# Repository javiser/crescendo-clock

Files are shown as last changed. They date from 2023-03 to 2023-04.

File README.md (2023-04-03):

# Crescendo Clock - an ESP32 based alarm clock to wake up gently

<p align="center">
  <a href="#highlights">Highlights</a> •
  <a href="#how-to-use">How to use</a> •
  <a href="#main-components">Main components</a> •
  <a href="#compiling-and-customizing-the-software">Compiling and customizing SW</a> •
  <a href="#credits-and-acknowledgment">Credits</a><br>
</p>

**A self-made clock with a gentle crescendo wake up alarm**

https://user-images.githubusercontent.com/75809109/229468796-8822e73a-d802-4b9b-99c0-e9e2a0a7bf44.mp4

## Highlights
- Gentle alarm-clock with a crescendo function to wake up slowly and peacefully
- Simplified user interaction with a rotary encoder with a button. No touch display, no need for 10 different buttons
- Convenient WiFi connection via WPS. Credentials are then stored in NVS flash of the board
- Custom 3D printed case
- Integration with home assistant via MQTT messages (i.e. to create a wake up light effect)
- Light sensor to turn off display at adjust the brightness dynamically
- Written in C++ with ESP-IDF framework (no Arduino!) using Platformio + VSCode

## How to use
### Interaction elements
The user interaction with the crescendo clock takes place exclusively with the rotary encoder. This supports four possible actions:
- Left rotation
- Right rotation
- Short press / click
- Long press

Double press / click action is not supported.

### First step: connecting to WiFi
The crescendo clock sets the time automatically when it is connected to a WiFi. Manual time setting is not supported. The first time you power the clock or when the configured WiFi is not available, you will see a red wifi symbol on the right side of the screen:

https://user-images.githubusercontent.com/75809109/229468847-7dcbb47f-4164-47c6-b531-5e9feb42a694.mp4

Rotate the encoder just one click (left or right) and you will see a message "PRESS WPS". Press the WPS button of your router (or select the corresponding option of your specific router model) and wait a little bit until the WiFi connection has been established automatically. WiFi credentials are stored in NVS of ESP32 so that you will not need to repeat this step in the future. Only one credentials set can be stored: if you configure your clock for a different WiFi using the same procedure, the original WiFi credentials will no longer be present in the NVS.

### Using the crescendo clock 
This overview describes the basic usage of the crescendo clock:
| State | Rotation | Short press | Long press |
|---|:---:|:---:|:---:|
| Time | Increase brightness / activate WPS | Set alarm on/off | Enter alarm time |
| Set alarm time  | Change hour / minute of alarm | Next step | Cancel alarm setting |
| Alarm triggered | No effect | Snooze | No effect |
| Alarm snooze | Snooze cancelling sequence | Increase brightness | Snooze cancelling sequence |

Additional comments:
- If the alarm is active for triggering the alarm time is shown, otherwise it is hidden
- If the alarm is active and the remaining time until alarm triggering is less than 9 hours, this remaining "bed time" will be displayed as well
- After snoozing a triggered alarm, the alarm will be triggered again after 5 minutes if the snooze has not been cancelled
- The snooze process will continue indefinitely until it hasn't been cancelled
- The snooze cancelling sequence is like this: rotate the encoder in one direction, then long press the encoder and finally rotate the encoder in the opposite direction, waiting no longer than 3 seconds between steps. You will see one bar above the remaining time until new alarm trigger when the first step of the sequence has been successfully performed and a second bar after the second step. When the final step is performed, the remaining "snooze time" will just disappear and the alarm time will disappear as well (see the video at the beginning of this page)
- After the snooze cancelling sequence the alarm is deactivated until you activate it again manually. You need to set the alarm every single day! Remember, I designed the clock following my ideal concept of a clock and this is the way I like it.

### MQTT integration
The crescendo clock does not subscribe to any MQTT message. Instead, it sends two different messages:
- One message with the topic `wecker/wake_up` when the alarm is triggered. This will be send every time the alarm is triggered, also after the snooze phase.
- Another message with the topic `wecker/alarm_off` when the snooze cancelling sequence is complete and the alarm has been completely deactivated.

## Main components
These are the main electrical components used in this project:
- [Seeed Studio XIAO ESP32C3 board](https://wiki.seeedstudio.com/XIAO_ESP32C3_Getting_Started/)
- [Rotary encoder with board](https://www.ebay.de/itm/173657244984)
- [2.4 inch display with ILI9341 driver](https://www.waveshare.com/2.4inch-lcd-module.htm)
- [DFRobot's DFPlayer Mini](https://www.dfrobot.com/product-1121.html)
- [Light sensor](https://www.adafruit.com/product/2748)
- [Mini-speaker](https://www.ebay.de/itm/313914312809)

See the [detailed description](hardware/README.md) in the hardware folder for more information about schematics, PCB, 3D printed case, detailed assembly instructions and other design considerations.

## Compiling and customizing the software
Basic knowledge about platformio, ESP-IDF development and ESP32 boards is required. This project has been tested only under a Linux environment. In order to compile this project you will need:
- Your populated PCB board with the ESP32C3 board connected to the PC via USB
- Visual Studio Code with platformio extension installed and Espressif platform 6.1 installed. Platform updates may cause the code to break, this happened during development several times. If you want to avoid this, set the line `platform = espressif32@=6.1.0` in the file [platformio.ini](platformio.ini)

Just build and upload the code! If you upload to code to the board with no hardware connected to it (display, encoder, etc.) you should at least be able to see some basic debug messages via Serial Monitor related to the failed WiFi connection.

### Waking melodies and other settings
In this repository there is not any audio file for the waking melody. In the [DFPlyer mini wiki](https://wiki.dfrobot.com/DFPlayer_Mini_SKU_DFR0299) you will find instructions on how to create your own files (see chapter ["Copy your mp3 into you micro SD card"](https://wiki.dfrobot.com/DFPlayer_Mini_SKU_DFR0299#target_6)). I have a folder called `mp3` in the SD-card and inside it a single file called `0001.mp3`. You can add further files and change the value of `melody_nr` in the `settings` struct in [src/clock_machine.hpp](src/clock_machine.hpp) and add the corresponding mp3 file. In case you want a confirmation sound when you activate the alarm, then set the settings variable `alarm_set_confirmation_sound` to true and make sure a (short) `0101.mp3` file exists. This does not work really well, as the DFPlayer doesn't seem to like short audio files, and I will most likely remove this feature in a near future.

Furthermore, you can change also the snooze time (default = 5 minutes) and the "crescendo speed" in the same `settings` structure. These are fixed values and cannot be changed after compilation.

## Credits and acknowledgment
For this project I have used the inspiration and code from many other projects and sources: 
- I looked up and partly copied some code from the official esp-idf examples contained in https://github.com/espressif/esp-idf/tree/master/examples (mainly those related to SNTP, WPS, MQTT and Wifi functions)
- For the rotary encoder I used some code from https://github.com/LennartHennigs/ESPRotary as well as from https://github.com/craftmetrics/esp32-button. The code from https://github.com/DavidAntliff/esp32-rotary-encoder was also a good source of inspiration
- For the finite state machine implementation I borrowed the ideas from https://www.aleksandrhovhannisyan.com/blog/finite-state-machine-fsm-tutorial-implementing-an-fsm-in-c/ as well as from https://stackoverflow.com/questions/14676709/c-code-for-state-machine
- For the DFPlayer module used this datasheet to look up the specifications https://cdn.shopify.com/s/files/1/1509/1638/files/MP3_Player_Modul_Datenblatt.pdf?10537896017176417241. I also found some undocumented functions in the library implementation in https://github.com/DFRobot/DFRobotDFPlayerMini
- [Adafruit](https://www.adafruit.com/) for the many resources I used for the creation of custom fonts and symbols (see a [more detailed description](fonts/README.md) in the resources folder) as well as for the great inspiration from their [PyPortal Alarm Clock](https://learn.adafruit.com/pyportal-alarm-clock), out of which I created a very first concept of this kind of crescendo clock. 

## License
Copyright (c) 2023 javiser
`crescendo-clock` is distributed under the terms of the MIT License.

See the [LICENSE](LICENSE) for license details.

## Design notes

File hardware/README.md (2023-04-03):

# Hardware

<p align="center">
  <a href="#schematics-and-pcb-design">Highlights</a> •
  <a href="#board-assembly">Board assembly</a> •
  <a href="#3d-printed-case">3D printed case</a> •
  <a href="#final-assembly">Final assembly</a> •
  <a href="#modifications">Modifications</a><br>
</p>

## Schematics and PCB design
<p float="left">
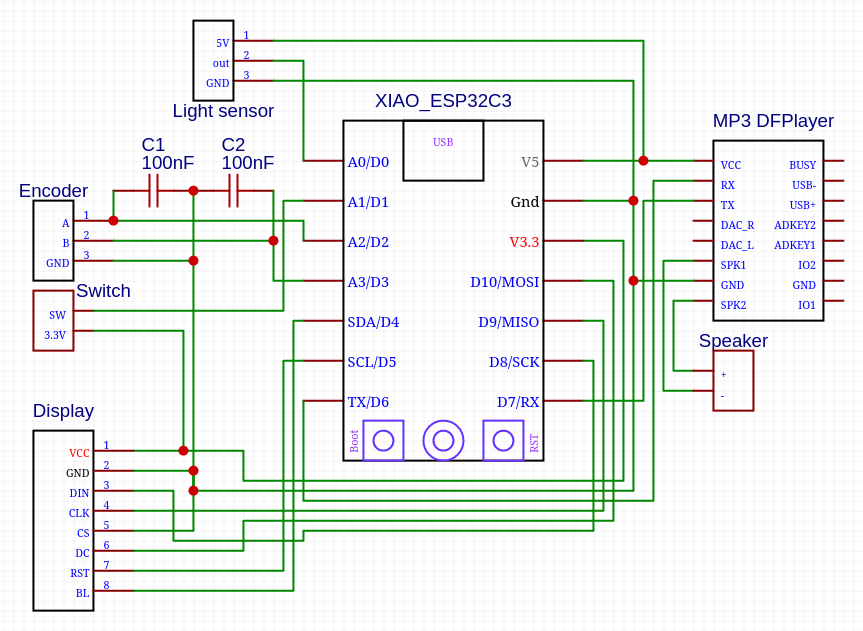
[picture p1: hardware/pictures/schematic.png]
    
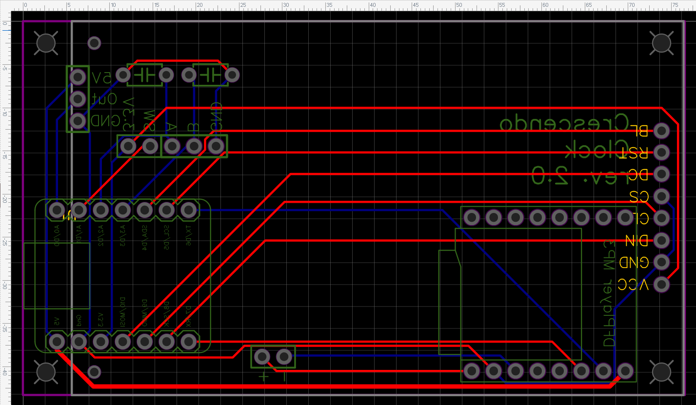
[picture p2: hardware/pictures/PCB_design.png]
    
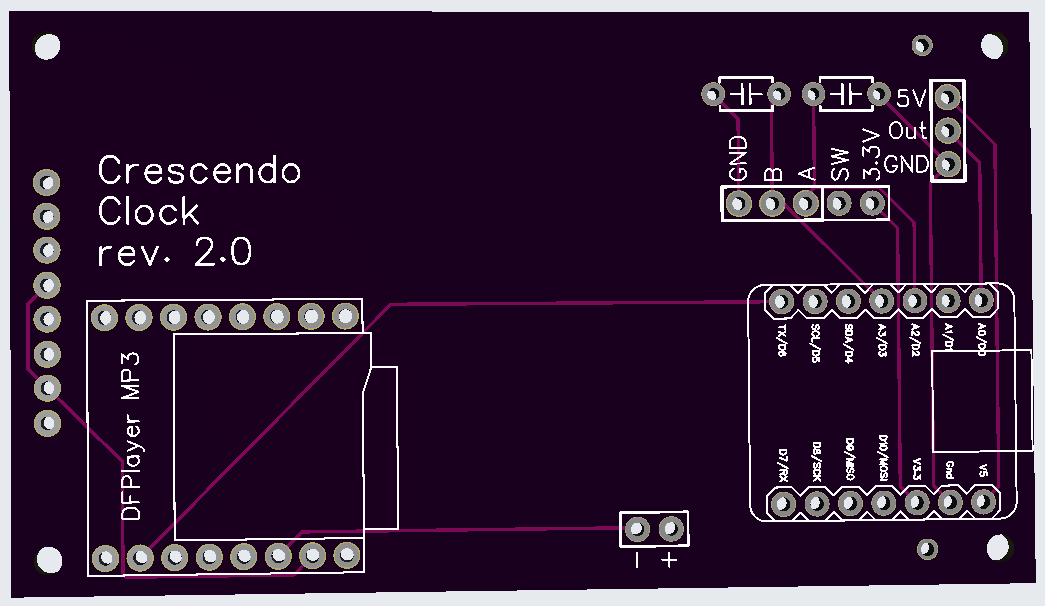
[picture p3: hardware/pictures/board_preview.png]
    
</p>

A couple of mentions to design considerations:

- The capacitors were used in a previous design to add some debouncing. In the current [rotary encoder](https://www.ebay.de/itm/173657244984) used, these capacitors are already include and are not soldered anymore
- With the exception of some SPI pins for the [display](https://www.waveshare.com/2.4inch-lcd-module.htm) and the fact that the light sensor needs an analog input, which pins to use on the ESP32 board should is actually a very free decision
- The design was made using EasyEDA and the [created GERBER files](PCB/Gerber_PCB_Crescendo_Clock_Board_rev2.0.zip) and the board manufactured by [JLCPCB](https://jlcpcb.com). This is the result:

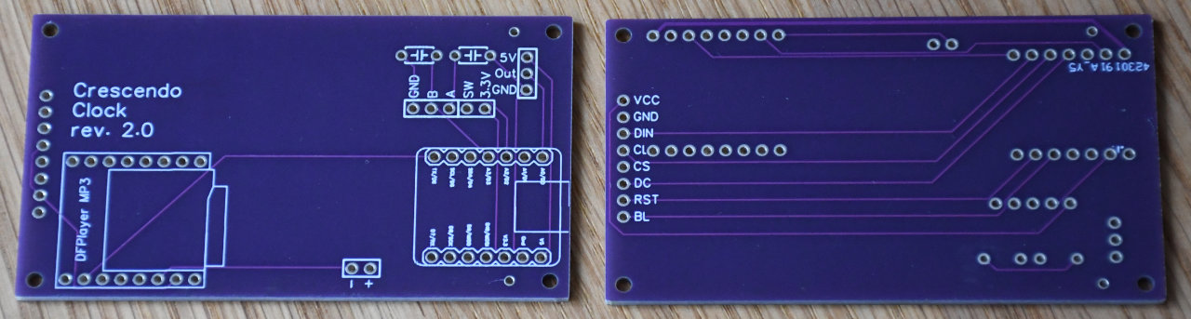
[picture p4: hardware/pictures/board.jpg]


## Board assembly

### Display connector removal
The big connector on the rear side of the display is not needed and needs to be removed in order to build the board properly. Just cut the the pins with some pliers and then you can slide out the connector:
<p float="left">
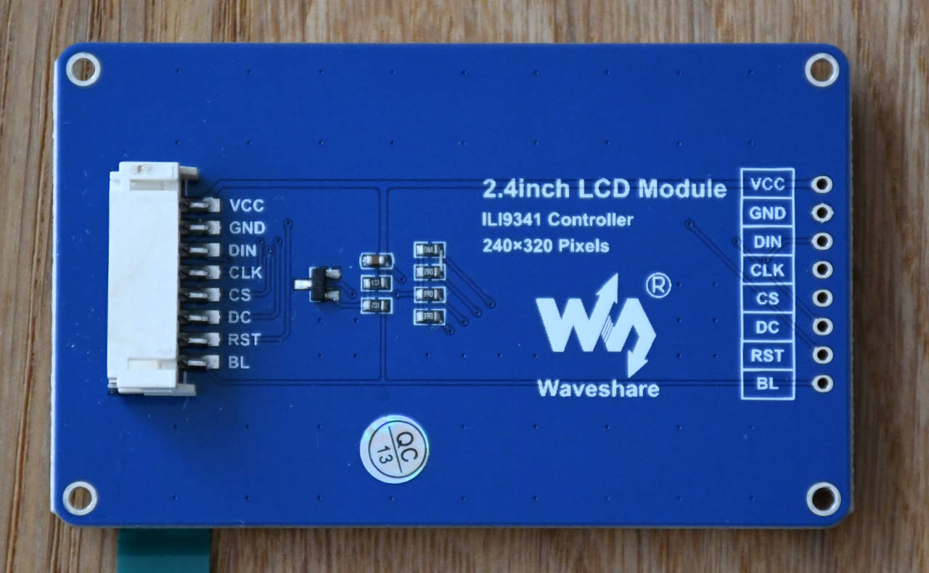
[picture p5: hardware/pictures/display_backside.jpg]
    
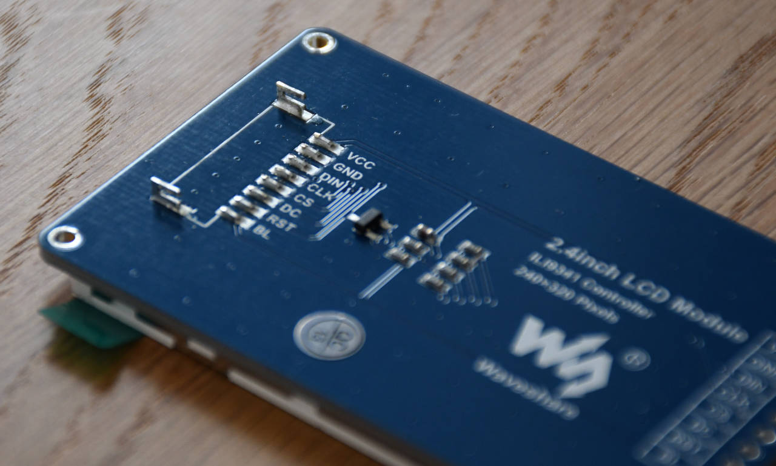
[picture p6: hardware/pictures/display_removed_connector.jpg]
    
</p>

### Soldering all together
1. Solder the 1x8 pin male header on the display and 2 additional 1x1 ones as support. You can use the still empty PCB board as a holder:
<p float="left">
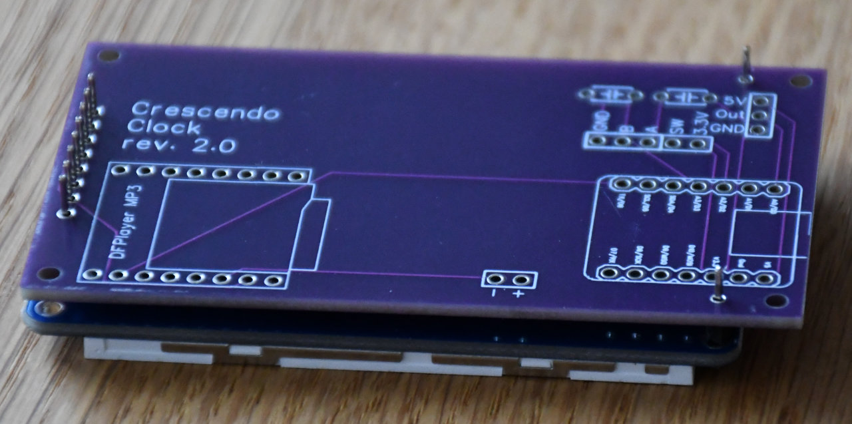
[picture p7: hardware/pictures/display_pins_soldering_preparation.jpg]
    
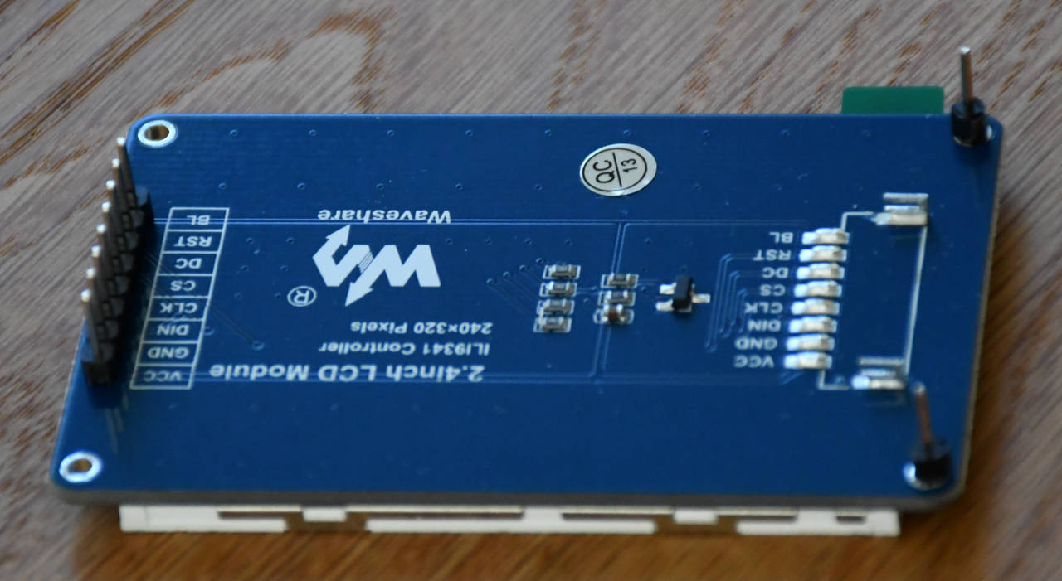
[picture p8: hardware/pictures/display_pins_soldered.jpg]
    
</p>

2. Solder a 1x3 90° pin male header on the [light sensor breakout board](https://www.adafruit.com/product/2748). Pay attention to the orientation!
<p float="left">
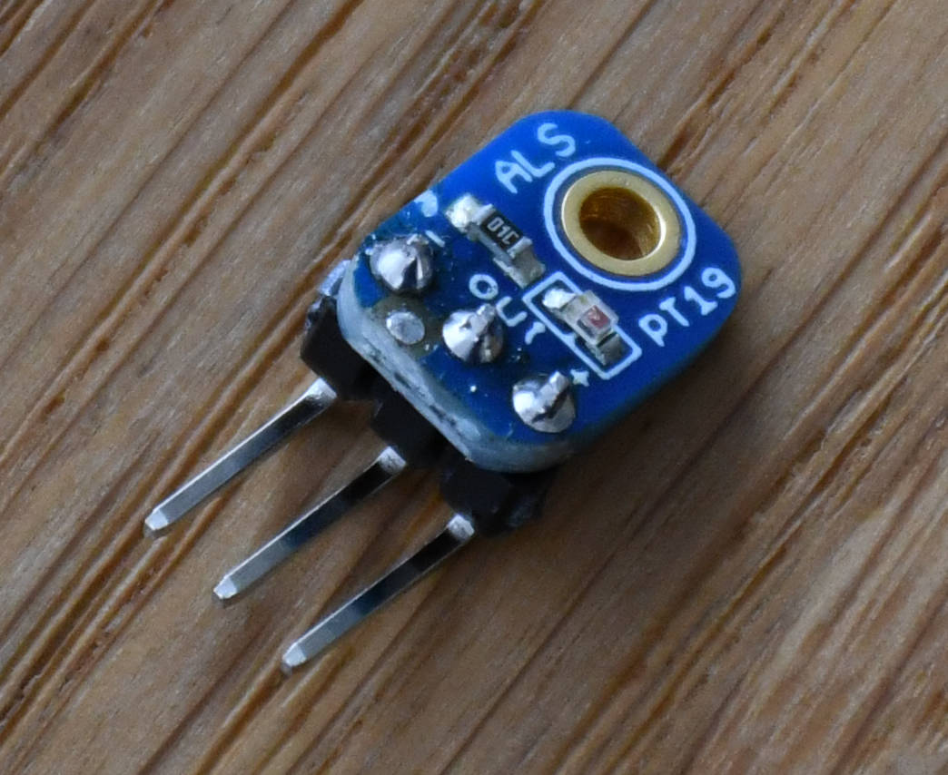
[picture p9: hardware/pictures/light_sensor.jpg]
    
</p>

3. Solder all components to the PCB board and trim the excess length of the pins to make room for the display board
<p float="left">
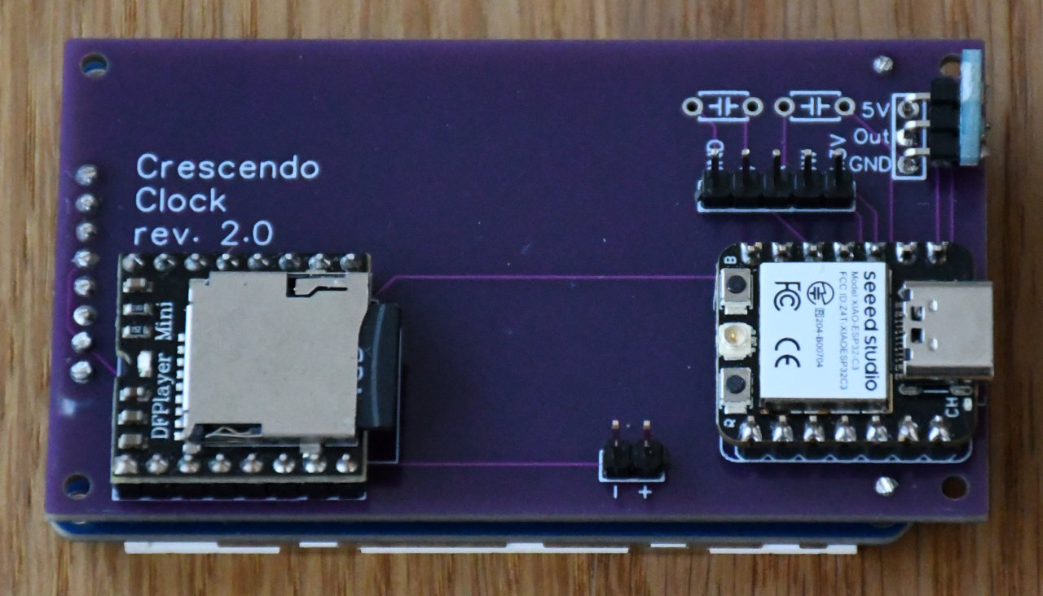
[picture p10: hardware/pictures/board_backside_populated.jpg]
    
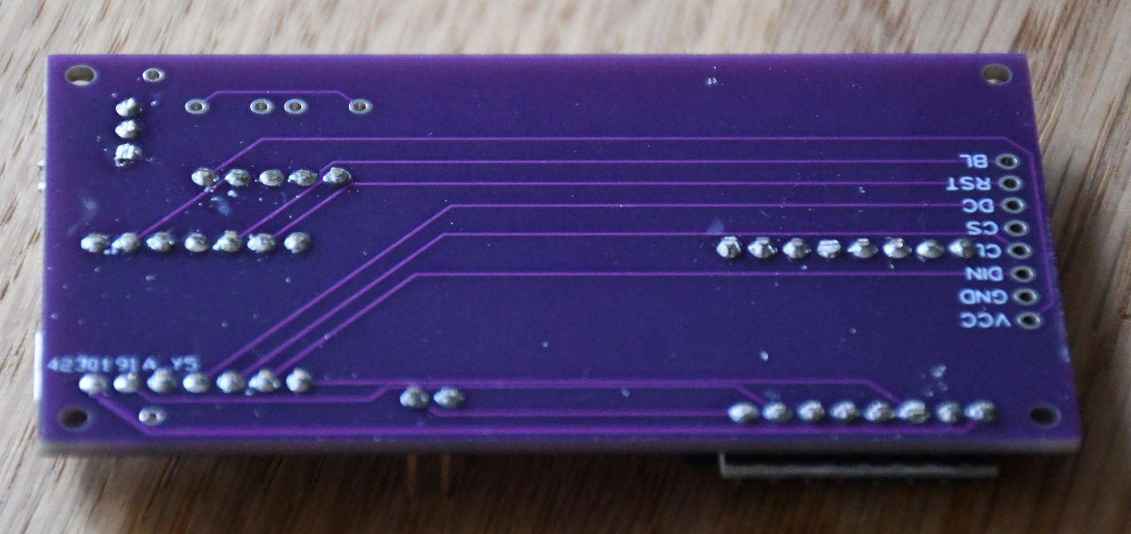
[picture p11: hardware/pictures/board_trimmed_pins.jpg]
    
</p>

4. Solder the display on the other side of the board. 
<p float="left">
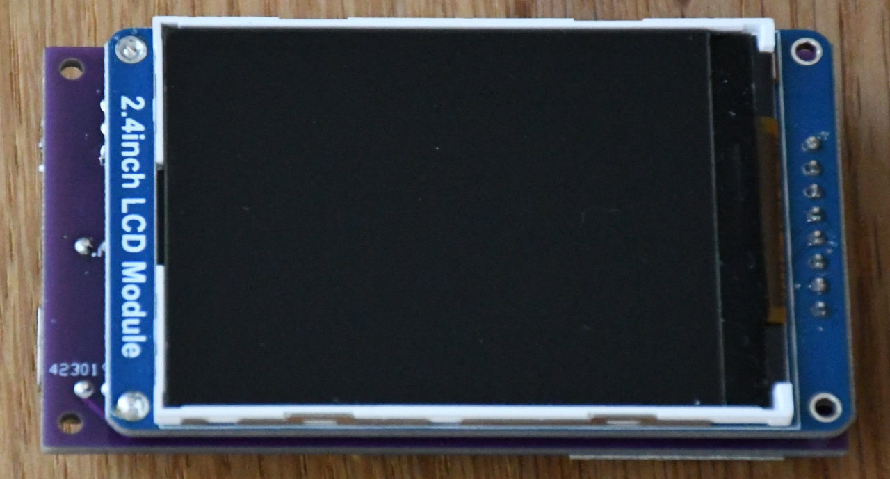
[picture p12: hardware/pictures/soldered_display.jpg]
    
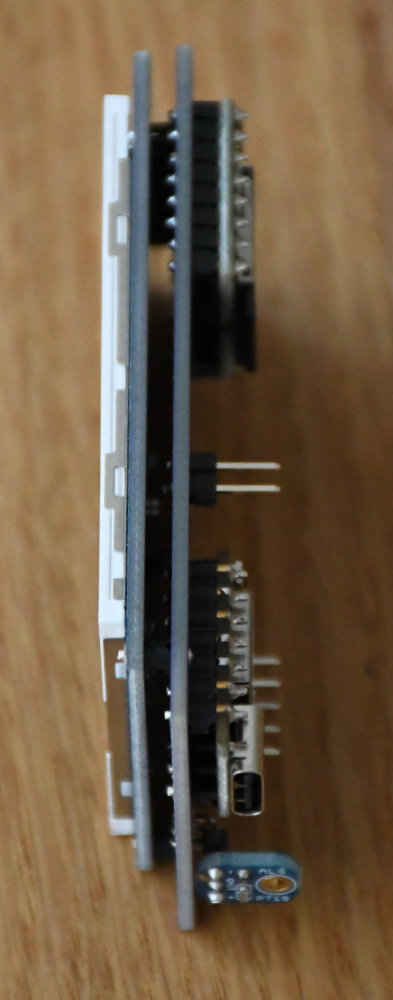
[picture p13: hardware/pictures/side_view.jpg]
    
</p>

5. Prepare a connection cable with 5 pins for the connection between the board and the rotary encoder breakout. Again, I used dupont connectors for this:

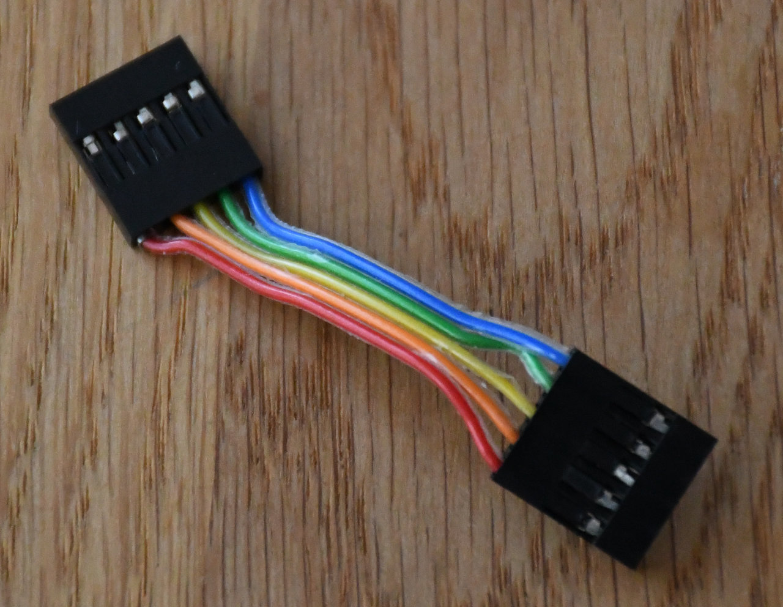
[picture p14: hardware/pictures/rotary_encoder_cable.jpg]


6. If necessary, change the connector of the mini-speaker. I used dupont connectors for this:
   
<p float="left">
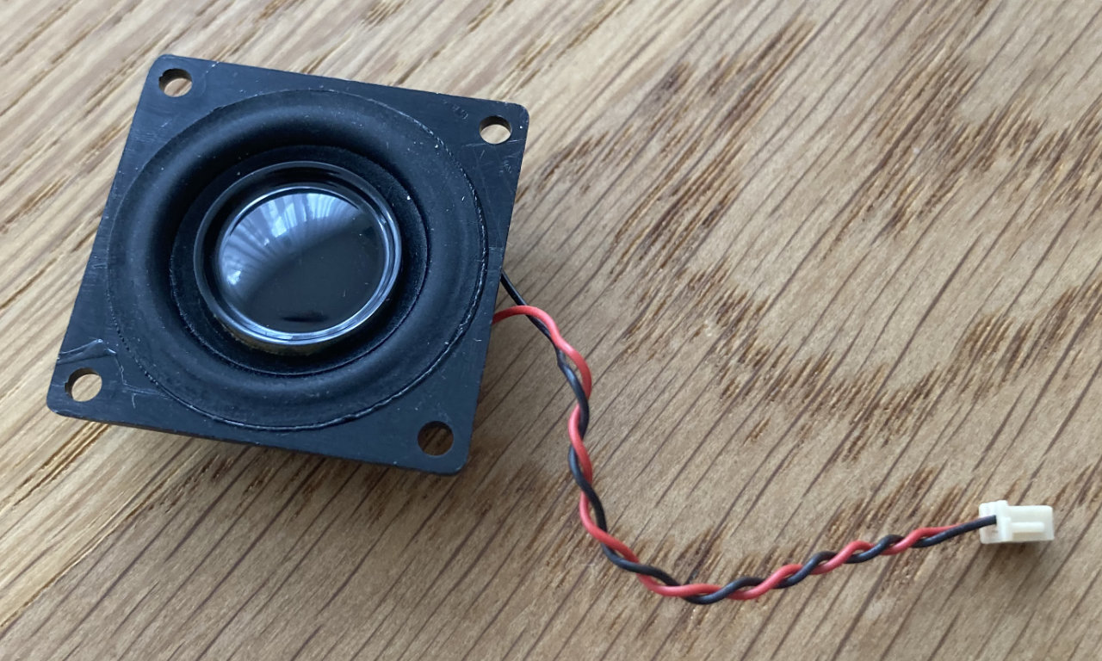
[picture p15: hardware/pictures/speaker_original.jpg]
    
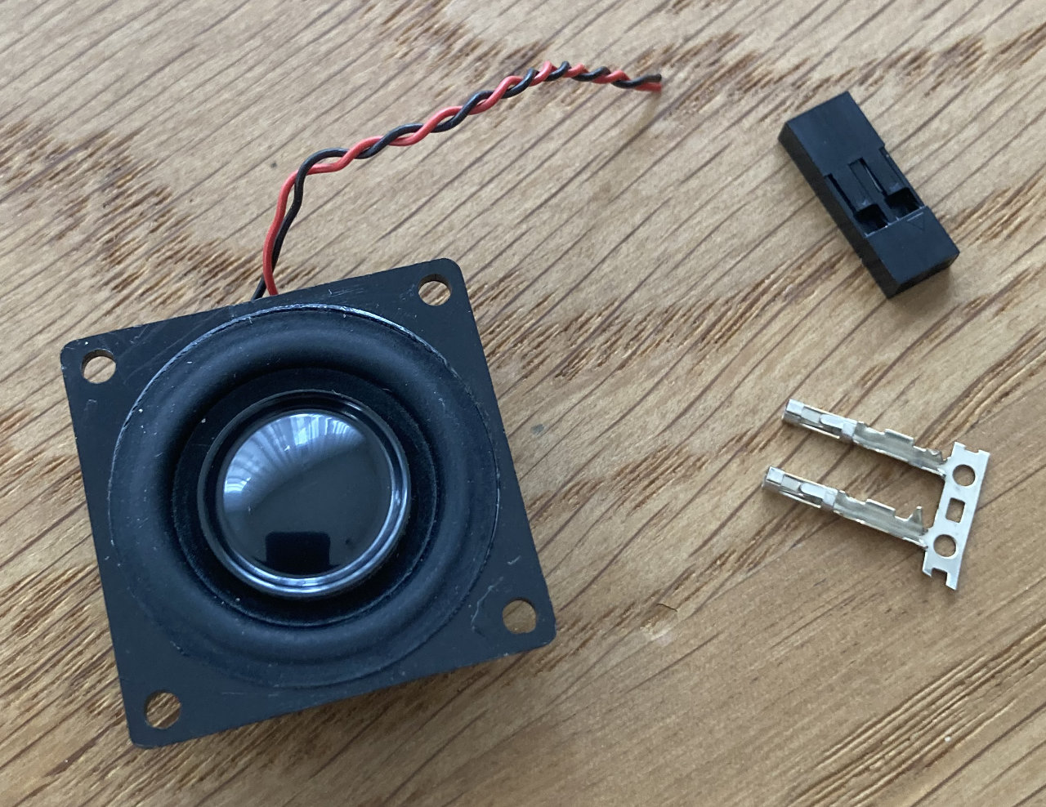
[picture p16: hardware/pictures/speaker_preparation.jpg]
    
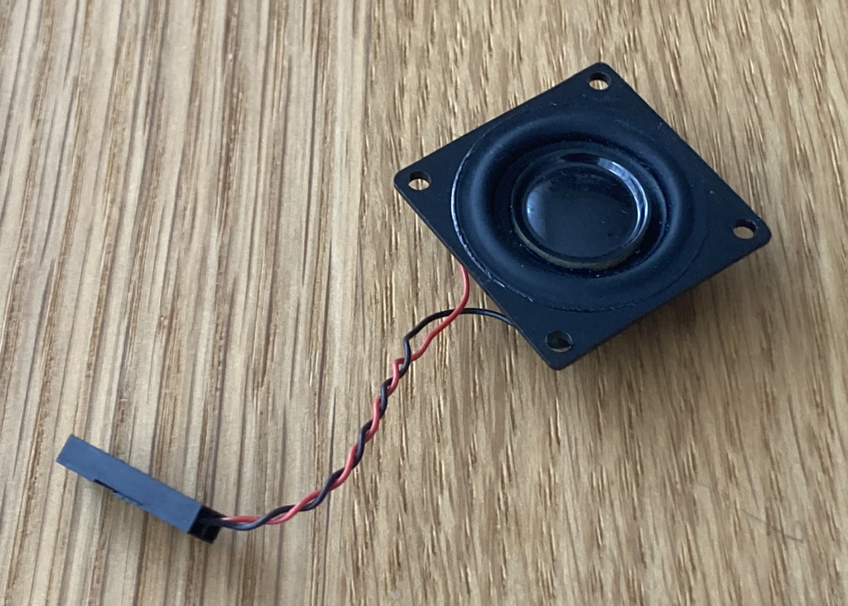
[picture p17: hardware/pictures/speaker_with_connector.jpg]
    
</p>

7. After that it would be a good time to do a sanity check and connect everything together, flash the SW into the board and check whether everything is working as expected:
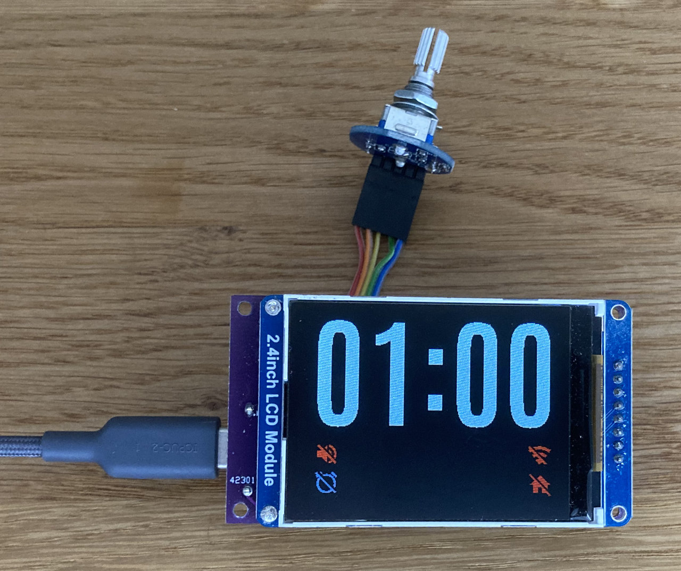
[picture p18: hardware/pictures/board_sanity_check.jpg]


## 3D printed case
STL files for the [case](3D/case.stl), the [rear cover](3D/rear_cover.stl) and the [knurled rotary botton](3D/knurled_button.stl) are available:
<p float="left">
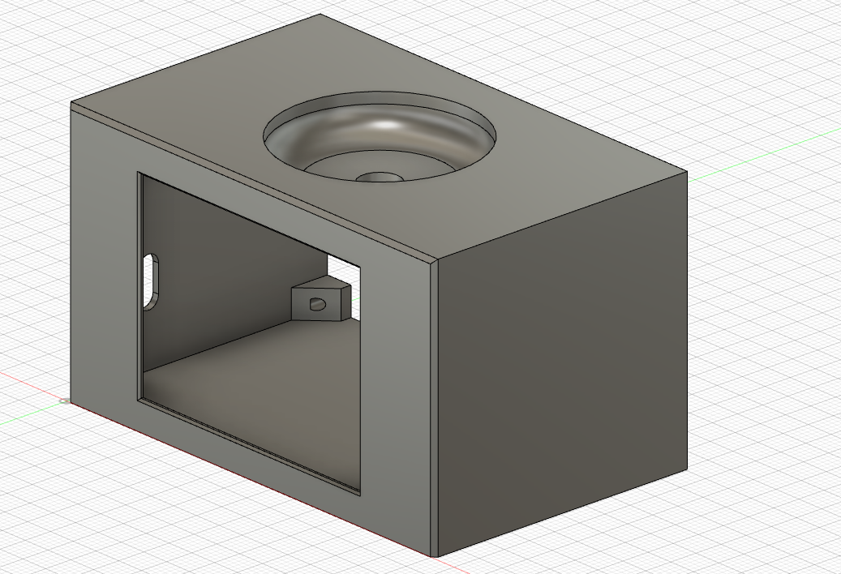
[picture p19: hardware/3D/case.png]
    
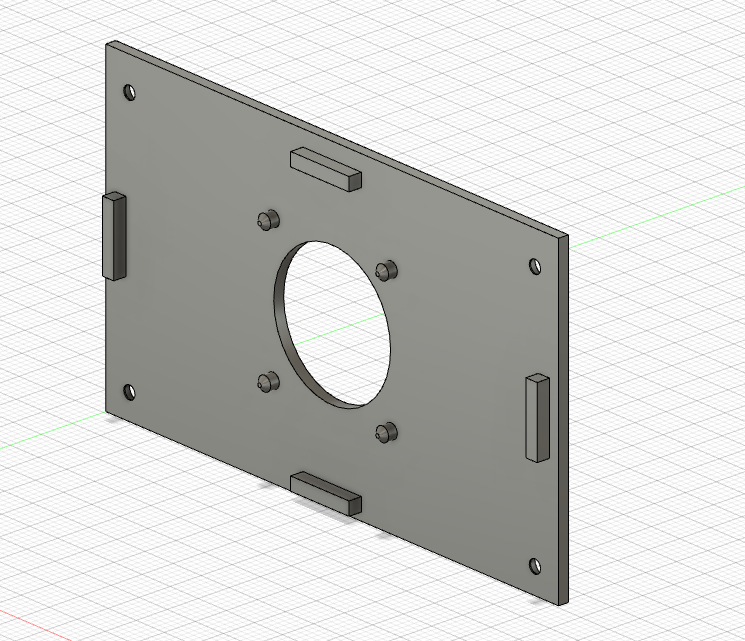
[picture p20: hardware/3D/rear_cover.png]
    
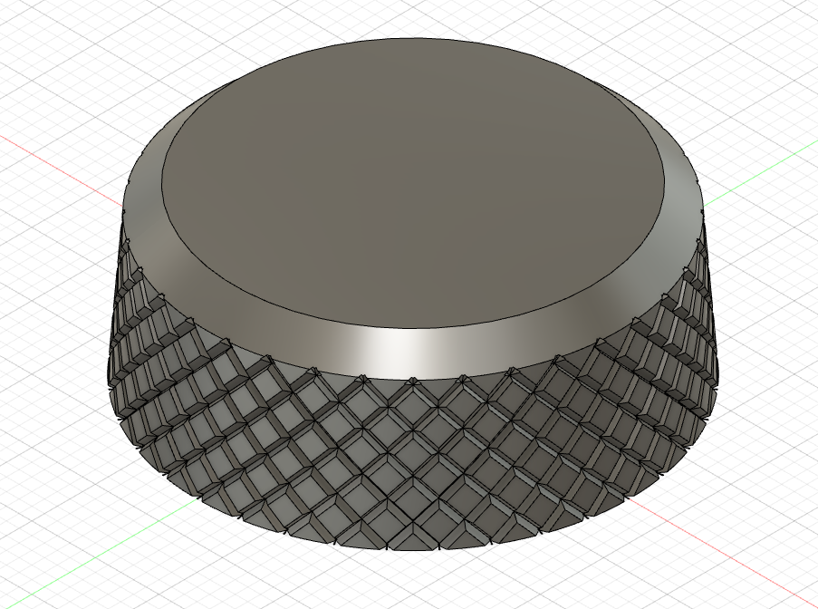
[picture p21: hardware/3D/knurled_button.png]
    
</p>
I printed these with PLA using an Ender 3 v2. Pay attention to the orientation when slicing: the clock front side, the outside face of the rear cover as well as the top face of the button should be your first layer. You may use supports for the big case, I didn't use any and it went ok.

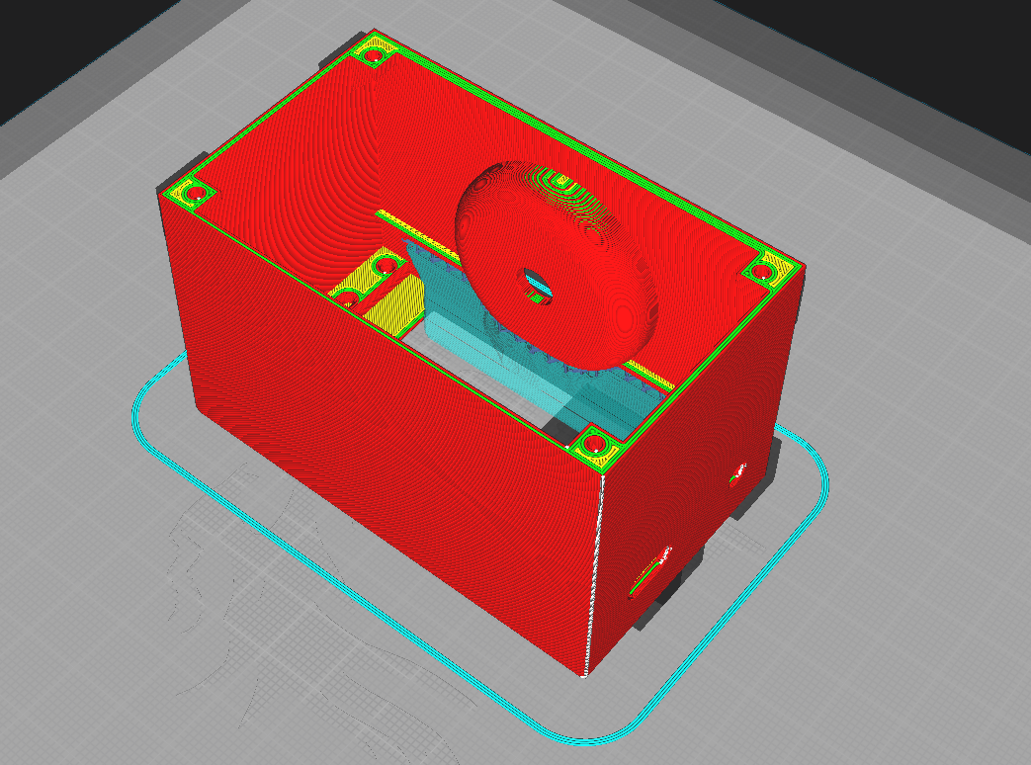
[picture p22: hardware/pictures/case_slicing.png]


You can find the original Fusion 360 files in the [3D folder](3D) as well.

## Final assembly

1. Put an SD card with the necessary audio files. See <a href="../#waking-melodies-and-other-settings">Waking melodies and other settings chapter</a> of the main README for more instructions.
2. Slide in the finished board and screw it into the case using 4 M2.5x8 screws

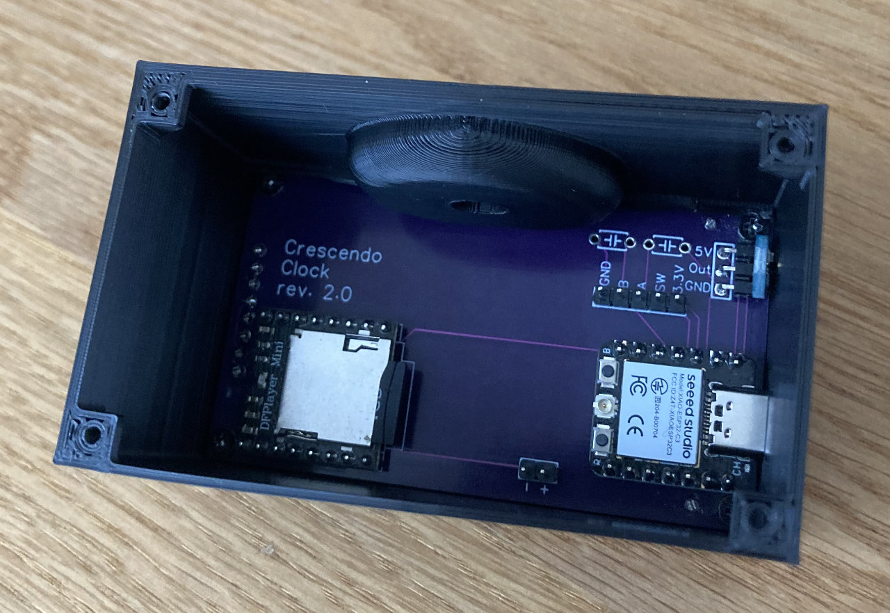
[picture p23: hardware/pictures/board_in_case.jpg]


3. Attach the ESP32 antenna on one side of the case and connect it to the board

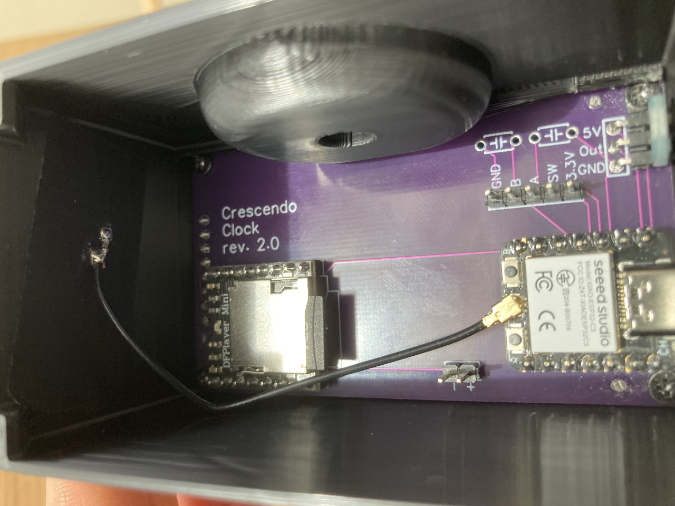
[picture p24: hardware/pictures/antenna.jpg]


4. Connect the cables to the rotary encoder and slide it into its place. Put the washer and hex nut and tighten it. Make sure it is perpendicular. Insert the button into the shaft



5. Attach the speaker on the rear cover. Pay attention to the orientation, since the rear cover has an upper and a lower part and you want the cables coming out of the lower part. It should be a tight fit into the pins, otherwise use some strong glue to make sure it stays attached



6. Connect everything together sure everything is connected  



7. Close the cover using 4 M2x4 screws

## Modifications
The components used are just what I could get my hands on or what made sense to me. Here some considerations:

- It should be possible to use any other ESP32 board. The previous version used the [ESP-C3-32S-Kit ESP32 WiFi+Bluetooth Development Board](https://www.waveshare.com/esp-c3-32s-kit.htm). You just need to make sure that you have at least 11 pins available. The pin assignments defined in [clock_common.hpp](src/clock_common.hpp) will most likely need an adjustment. If you take a variant different from the ESP32C3 you might require more extensive changes as well
- Other LCD displays could work as well, specially if the same ILI9341 driver is used, but maybe other settings are required. Since the used library LovyanGFX supports a lot of different displays, changing to another display is just a matter of adjusting the configuration and, if the resolution changes, the layout (font sizes, symbol and text positions)
- In general any other component like the rotary encoder, speaker or the light sensor should be exchangeable with no or little effort

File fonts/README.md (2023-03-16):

# Fonts and symbols

## Sources for fonts and symbols
The fonts used in this projects have been downloaded from https://fonts.google.com/specimen/Antonio and then customized using FontForge (see chapter below for instructions):
- [Antonio-Semibold](Antonio-SemiBold.ttf) is used for the time visualization. The glyphs have been modified to have a constant width
- [Antonio-Regular](Antonio-Regular.ttf) is used for the "secondary" times: alarm, snooze and bed times. Also the symbols have been embedded into this font and the glyphs have been modified to have a constant width as well
- [Antonio-Light](Antonio-Light.ttf) is used only for the "PRESS WPS" message and has not been customized or modified at all

The [symbols](symbols) are material design icons from https://pictogrammers.com/library/mdi/ which have been imported as glyphs in the fonts

## Tooling

The main tool used for the fonts and symbols customization is [FontForge](https://fontforge.org/en-US/). With this tool it is possible (amongst many other things!) to:
- Remove unnecessary glyphs
- Change the glyph width to allow for consistent spacing and layout
- Import icons and symbols, in our case in SVG format, to be able to print symbols as if they were characters
- Modify these glyphs: scaling, rotating, etc. and create new symbols this way
- Generate a new TTF file for further processing

When the customized fonts are finished, the required characters can be converted to a header file which can be included directly in the code, using the [fotoconvert tool from Adafruit](https://github.com/adafruit/Adafruit-GFX-Library/tree/master/fontconvert). First build the program with `make` and then execute these scripts to generate the required header files:
```
./fontconvert Antonio-SemiBold.ttf 75 48 58 > Antonio_SemiBold75pt7b.h
./fontconvert Antonio-Regular.ttf 26 32 70 > Antonio_Regular26pt7b.h
./fontconvert Antonio-Light.ttf 16 69 87 > Antonio_Light16pt7b.h
```
Please note that it is necessary to specify a range of characters. For big fonts it is necessary to pay attention to the flash size of the generated fonts. The fotoconvert tool does not support multiple ranges, which could help minimize the size of the files.

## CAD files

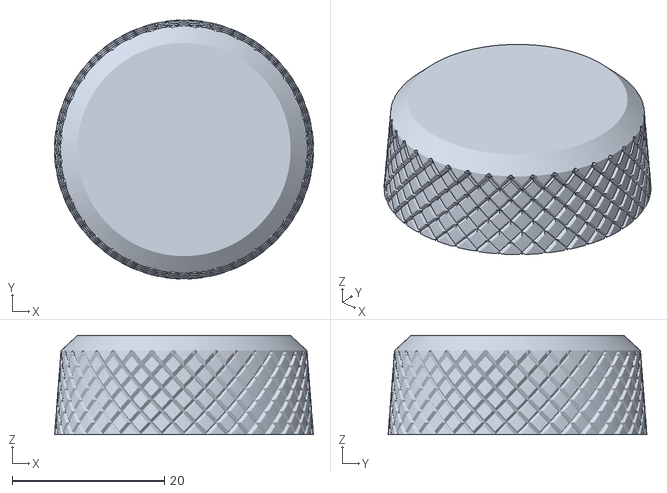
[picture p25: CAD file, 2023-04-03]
hardware/3D/knurled_button.stl
34.0 x 34.0 x 13.0

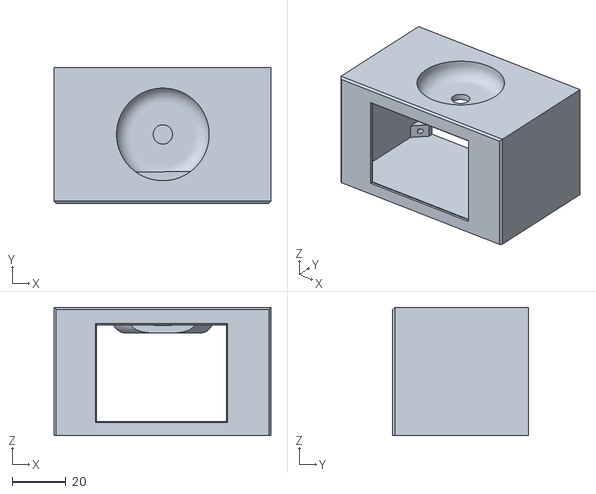
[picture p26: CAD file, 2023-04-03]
hardware/3D/case.stl
80.6 x 50.4 x 47.7

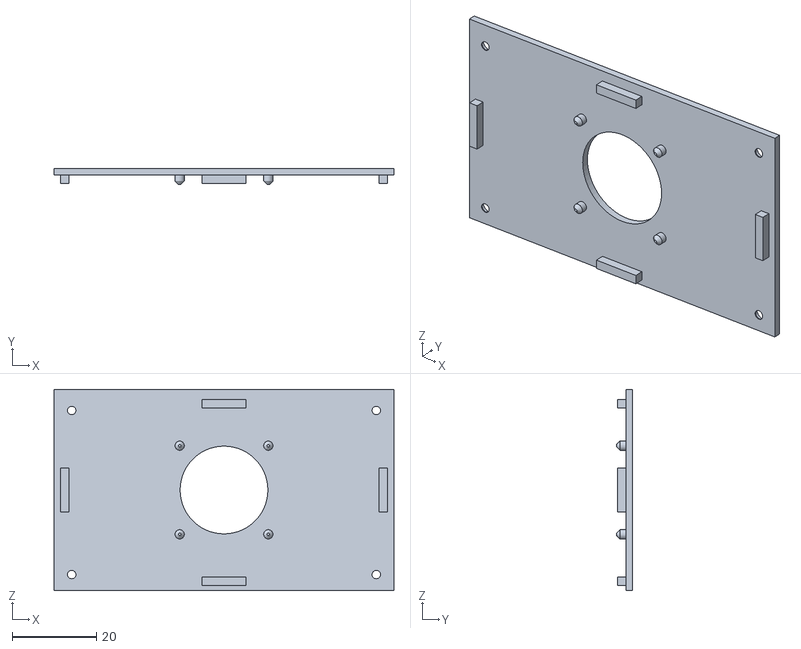
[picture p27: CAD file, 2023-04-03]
hardware/3D/rear_cover.stl
80.6 x 3.80 x 47.7

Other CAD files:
hardware/3D/case.f3z

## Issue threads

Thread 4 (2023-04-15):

Create mirrored PCB and case version

javiser, 2023-04-15:
There might be people who need the cable on the other side of the case. In that case, mirrored PCB and a case designs would be required.

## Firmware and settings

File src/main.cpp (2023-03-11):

#include "freertos/FreeRTOS.h"
#include "freertos/task.h"
#include "nvs_flash.h"
#include <wifi_time.hpp>
#include <rotary_encoder.hpp>
#include "clock_machine.hpp"
#include "clock_machine_states.hpp"
#include "clock_common.hpp"

extern "C" void app_main() {
    // Initialize NVS (needs to be done first thing in main!)
    esp_err_t ret = nvs_flash_init();
    if (ret == ESP_ERR_NVS_NO_FREE_PAGES || ret == ESP_ERR_NVS_NEW_VERSION_FOUND) {
        // NVS partition was truncated and needs to be erased
        // Retry nvs_flash_init
        ESP_ERROR_CHECK(nvs_flash_erase());
        ret = nvs_flash_init();
    }
    ESP_ERROR_CHECK(ret);

    // Initialise the rotary encoder device with the GPIOs for A and B signals
    RotaryEncoder encoder;
    QueueHandle_t event_queue = encoder.init(ROT_ENC_A_GPIO, ROT_ENC_B_GPIO, ROT_ENC_BUTTON_GPIO, ROT_ENC_BUTTON_INVERTED);

    ClockMachine machine(&encoder);  // By default a clock machine starts in state "TIME"
    rotary_encoder_event_t event;

    while (1) {
        if (xQueueReceive(event_queue, &event, 10 / portTICK_PERIOD_MS) == pdTRUE) {
            switch (event.type) {
                case ENCODER_ROTATION:
                    machine.encoderRotated(event.position, event.direction);
                    break;
                case BUTTON_SHORT_PRESS:
                    machine.buttonShortPressed();
                    break;
                case BUTTON_LONG_PRESS:
                    machine.buttonLongPressed();
                    break;
            }
        }

        // Perform whatever cyclic activities or checks are needed for this state
        machine.run();
        vTaskDelay(10 / portTICK_PERIOD_MS);
    }
}

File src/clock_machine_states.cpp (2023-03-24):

#include "clock_machine_states.hpp"

//--------------//
//  TIME STATE  //
//--------------//

ClockState& TimeState::getInstance() {
    static TimeState singleton;
    return singleton;
}

void TimeState::enter(ClockMachine* clock) {
    clock->getDisplay()->updateContent(D_E_TIME, &clock->stored_time, D_A_ON);
}

void TimeState::run(ClockMachine* clock) {
    if (clock->is_alarm_set &&
        (clock->stored_time.hour == clock->alarm_time.hour) &&
        (clock->stored_time.minute == clock->alarm_time.minute)) {
        clock_time_t bed_time = clock->getTimeToAlarm(clock->stored_time, clock->alarm_time);
        clock->getDisplay()->updateContent(D_E_BED_TIME, &bed_time, D_A_OFF);
        clock->setState(AlarmState::getInstance());
    }
    else if (clock->is_alarm_set && clock->time_has_changed)
    {
        clock_time_t bed_time = clock->getTimeToAlarm(clock->stored_time, clock->alarm_time);
        clock->getDisplay()->updateContent(D_E_BED_TIME, &bed_time, D_A_ON);
    }
    
}

void TimeState::timerExpired(ClockMachine* clock) {
    clock->getDisplay()->setIncreasedBrightness(false);
}

void TimeState::buttonShortPressed(ClockMachine* clock) {
    if (clock->getDisplay()->isDisplayOn()) {
        // Invert the alarm state but only if the display was already on
        clock->is_alarm_set = !clock->is_alarm_set;
        display_action_t action = clock->is_alarm_set ? D_A_ON : D_A_OFF;        
        clock->getDisplay()->updateContent(D_E_ALARM_TIME, &clock->alarm_time, action);
        clock_time_t bed_time = clock->getTimeToAlarm(clock->stored_time, clock->alarm_time);
        clock->getDisplay()->updateContent(D_E_BED_TIME, &bed_time, action);
    }
    clock->getDisplay()->setIncreasedBrightness(true);
    clock->triggerTimer(3000);
}

void TimeState::buttonLongPressed(ClockMachine* clock) {
    clock->setState(SetAlarmState::getInstance());
}

void TimeState::encoderRotated(ClockMachine* clock, rotary_encoder_pos_t position, rotary_encoder_dir_t direction) {
    // If wifi is already connected, just use this as a temporary brightness increaser. Otherwise go to Wifi WPS setting state
    if (clock->getWifiTime()->isWifiConnected()) {
        clock->getDisplay()->setIncreasedBrightness(true);
        clock->triggerTimer(3000);
    } else {
        clock->setState(WPSState::getInstance());
    }
}

void TimeState::exit(ClockMachine* clock) {
}

TimeState::~TimeState() {}


//-------------//
//  WPS STATE  //
//-------------//

ClockState& WPSState::getInstance() {
    static WPSState singleton;
    return singleton;
}

void WPSState::enter(ClockMachine* clock) {
    clock->getDisplay()->updateContent(D_E_BED_TIME, &(clock->alarm_time), D_A_OFF); // alarm time as dummy value
    blink = true;
    clock->getDisplay()->updateContent(D_E_WIFI_SETTING, D_A_ON);
    clock->getDisplay()->setIncreasedBrightness(true);
    clock->getWifiTime()->startWPS();
    clock->triggerTimer(500);
}

void WPSState::run(ClockMachine* clock) {
    // The moment we get a connection we leave this state
    if (clock->getWifiTime()->isWifiConnected()) {
        // Save the acquired credentials in NVS
        clock->saveWifiCredentialsInNVS();
        clock->setState(TimeState::getInstance());
    }
}

void WPSState::timerExpired(ClockMachine* clock) {
    blink = !blink;
    display_action_t action = blink ? D_A_ON : D_A_OFF;
    clock->getDisplay()->updateContent(D_E_WIFI_SETTING, action);
    clock->triggerTimer(500);
}

void WPSState::buttonShortPressed(ClockMachine* clock) {
}

void WPSState::buttonLongPressed(ClockMachine* clock) {
}

void WPSState::encoderRotated(ClockMachine* clock, rotary_encoder_pos_t position, rotary_encoder_dir_t direction) {
    clock->getWifiTime()->stopWPS();
    clock->setState(TimeState::getInstance());
}

void WPSState::exit(ClockMachine* clock) {
    clock->getDisplay()->updateContent(D_E_WIFI_SETTING, D_A_OFF);
    display_action_t action = clock->is_alarm_set ? D_A_ON : D_A_OFF;  
    clock_time_t bed_time = clock->getTimeToAlarm(clock->stored_time, clock->alarm_time);
    clock->getDisplay()->updateContent(D_E_BED_TIME, &bed_time, action);
    clock->checkWifiStatus(true);
}

WPSState::~WPSState() {}


//---------------//
//  ALARM STATE  //
//---------------//

ClockState& AlarmState::getInstance() {
    static AlarmState singleton;
    return singleton;
}

void AlarmState::enter(ClockMachine* clock) {
    clock->getDisplay()->setMaxBrightness(true);
    alarm_volume = 4;
    crescendo_counter = clock->settings.crescendo_factor;   // To force setting the volume in the next trigger
    clock->getPlayer()->loopTrack(clock->settings.melody_nr);
    clock->triggerTimer(10);  // Short trigger to avoid copying code that will be in the timerExpired method
    #ifdef MQTT_ACTIVE
    clock->getWifiTime()->sendMQTTAlarmTriggered();
    #endif
}

void AlarmState::run(ClockMachine* clock) {
}

void AlarmState::timerExpired(ClockMachine* clock) {
    if (crescendo_counter == clock->settings.crescendo_factor) {
        crescendo_counter = 0;
        if (alarm_volume < 30) {
            alarm_volume++;
            clock->getPlayer()->setVolume(alarm_volume);
        }
    }
    crescendo_counter++;
    clock->triggerTimer(500);

    display_action_t action;
    action = alarm_symbol_direction ? D_A_OFF : D_A_ON;
    alarm_symbol_direction = !alarm_symbol_direction;
    clock->getDisplay()->updateContent(D_E_ALARM_ACTIVE, action);
}

void AlarmState::buttonShortPressed(ClockMachine* clock) {
    clock->setState(SnoozeState::getInstance());
}

void AlarmState::buttonLongPressed(ClockMachine* clock) {
}

void AlarmState::encoderRotated(ClockMachine* clock, rotary_encoder_pos_t position, rotary_encoder_dir_t direction) {
}

void AlarmState::exit(ClockMachine* clock) {
    clock->getPlayer()->stopTrack();
    clock->getDisplay()->setMaxBrightness(false);
    clock->getDisplay()->updateContent(D_E_ALARM_TIME, &clock->alarm_time, D_A_ON);
}

AlarmState::~AlarmState() {}


//----------------//
//  SNOOZE STATE  //
//----------------//

ClockState& SnoozeState::getInstance() {
    static SnoozeState singleton;
    return singleton;
}

void SnoozeState::enter(ClockMachine* clock) {
    snooze_leaving_step = SNOOZE_WAITING;
    clock->getDisplay()->setIncreasedBrightness(true);
    clock->triggerTimer(3000);  // To show the time 3 seconds after snoozing
    snooze_start_timer_s = (int64_t)(esp_timer_get_time() / 1000000);
    remaining_snooze_time_s = clock->settings.snooze_time_s;
}
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

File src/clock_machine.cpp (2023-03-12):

#include "nvs.h"
#include "clock_machine.hpp"
#include "clock_machine_states.hpp"
#include "esp_log.h"

static const char *TAG = "clock_machine";

ClockMachine::ClockMachine(RotaryEncoder* encoder_ref) {
    // This will retrieve all stored data from NVS
    if (readNVSValues() == ESP_ERR_NVS_NOT_FOUND) {
        // This is the fault we get when we try to read data which has not yet been written in the memory. In that case we accept that and rewrite
        // the default values (all of them) into the flash. Then we try again but in this case we don't accept errors anymore and crash the SW
        writeNVSDefaultValues();
        ESP_ERROR_CHECK(readNVSValues());
    }

    // Initialize the wifi + sntp stuff
    wifi_time.init(&wifi_credentials);
    wifi_time.getTime(&stored_time);

    display.init();

    if (!audio_player.init(MP3_PLAYER_UART_PORT_NUM, MP3_PLAYER_TX, MP3_PLAYER_RX)) {
        ESP_LOGE(TAG, "There was an error initializing the MP3 player");
    }

    encoder = encoder_ref;

    // Upon clock start the alarm is always off
    display.updateContent(D_E_ALARM_TIME, &alarm_time, D_A_OFF);

    // We initialize with the opposite values to force a display update in the next run
    last_wifi_connected_status = !wifi_time.isWifiConnected();
    last_audio_online_status = !audio_player.isDeviceOnline();
    #ifdef MQTT_ACTIVE
    last_mqtt_connected_status = !wifi_time.isMQTTConnected();
    #endif

    state = static_cast<ClockState*>(new TimeState());
    state->enter(this);
}

esp_err_t ClockMachine::readNVSValues() {
    nvs_handle_t NVS_handle;

    esp_err_t err = nvs_open(NVS_STORAGE, NVS_READONLY, &NVS_handle);
    if (err != ESP_OK) return err;
    err = nvs_get_u8(NVS_handle, NVS_ALARM_HOUR, &alarm_time.hour);
    if (err != ESP_OK) return err;
    err = nvs_get_u8(NVS_handle, NVS_ALARM_MINUTE, &alarm_time.minute);
    if (err != ESP_OK) return err;
    size_t length = sizeof(wifi_credentials_t);
    err = nvs_get_blob(NVS_handle, NVS_WIFI_CREDENTIALS, &wifi_credentials, &length);

    nvs_close(NVS_handle);

    return err;
}

void ClockMachine::writeNVSDefaultValues() {
    // Default some values if values not set in NVS yet
    alarm_time.hour = 7;
    alarm_time.minute = 0;
    strcpy((char*)wifi_credentials.ssid, "Dummy");
    strcpy((char*)wifi_credentials.password, "123456");

    saveAlarmTimeInNVS();
    saveWifiCredentialsInNVS();
}

void ClockMachine::saveAlarmTimeInNVS() {
    nvs_handle_t NVS_handle;

    ESP_ERROR_CHECK(nvs_open(NVS_STORAGE, NVS_READWRITE, &NVS_handle));
    ESP_ERROR_CHECK(nvs_set_u8(NVS_handle, NVS_ALARM_HOUR, alarm_time.hour));
    ESP_ERROR_CHECK(nvs_set_u8(NVS_handle, NVS_ALARM_MINUTE, alarm_time.minute));

    nvs_close(NVS_handle);
}

void ClockMachine::saveWifiCredentialsInNVS() {
    nvs_handle_t NVS_handle;

    ESP_ERROR_CHECK(nvs_open(NVS_STORAGE, NVS_READWRITE, &NVS_handle));
    ESP_ERROR_CHECK(nvs_set_blob(NVS_handle, NVS_WIFI_CREDENTIALS, &wifi_credentials, sizeof(wifi_credentials_t)));

    nvs_close(NVS_handle);
}

void ClockMachine::setState(ClockState& newState) {
    active_timer_us = 0;
    state->exit(this);   // do stuff before we change state
    state = &newState;   // change state
    state->enter(this);  // do stuff after we change state
}

void ClockMachine::checkTimeUpdate(void) {
    clock_time_t current_time;
    wifi_time.getTime(&current_time);

    if ((current_time.hour != stored_time.hour) ||
        (current_time.minute != stored_time.minute)) {
        stored_time.hour = current_time.hour;
        stored_time.minute = current_time.minute;
        display.updateContent(D_E_TIME, &stored_time, D_A_ON);
        time_has_changed = true;
    }
    else {
        time_has_changed = false;
    }
}

clock_time_t ClockMachine::getTimeToAlarm(clock_time_t current_time, clock_time_t alarm_time) {
    clock_time_t time_to_alarm;

    if (current_time.minute > alarm_time.minute) {
        alarm_time.minute += 60;
        current_time.hour++;
    }
    if (current_time.hour > alarm_time.hour)
        alarm_time.hour += 24;

    time_to_alarm.hour = alarm_time.hour - current_time.hour;
    time_to_alarm.minute = alarm_time.minute - current_time.minute;

    return time_to_alarm;
}

WifiTime* ClockMachine::getWifiTime() {
    return &wifi_time;
}

Display* ClockMachine::getDisplay() {
    return &display;
}

RotaryEncoder* ClockMachine::getEncoder() {
    return encoder;
}

DFPlayer* ClockMachine::getPlayer() {
    return &audio_player;
}

void ClockMachine::triggerTimer(uint16_t timer_ms) {
    active_timer_us = timer_ms * 1000;
    trigger_timestamp_us = esp_timer_get_time();
}

void ClockMachine::checkWifiStatus(bool force_update) {
    bool wifi_connected_status = wifi_time.isWifiConnected();
    if ((last_wifi_connected_status != wifi_connected_status) || force_update) {
        last_wifi_connected_status = wifi_connected_status;
        display_action_t wifi_action = wifi_connected_status ? D_A_ON : D_A_OFF;
        display.updateContent(D_E_WIFI_STATUS, wifi_action);
    }
}

void ClockMachine::run() {
    if (active_timer_us > 0 && (esp_timer_get_time() - trigger_timestamp_us) > active_timer_us) {
        active_timer_us = 0;
        state->timerExpired(this);
    } else {
        checkTimeUpdate();
        state->run(this);
    }
    // Keep track of wifi and mqtt status symbols
    checkWifiStatus(false);
    #ifdef MQTT_ACTIVE
    bool mqtt_connected_status = wifi_time.isMQTTConnected();
    if (last_mqtt_connected_status != mqtt_connected_status)
    {
        last_mqtt_connected_status = mqtt_connected_status;
        display_action_t mqtt_action = mqtt_connected_status ? D_A_ON : D_A_OFF; 
        display.updateContent(D_E_MQTT_STATUS, mqtt_action);
    }
    #endif

    // Keep track of audio player status, if not online then show this as error
    bool audio_online_status = audio_player.isDeviceOnline();
    if (last_audio_online_status != audio_online_status)
    {
        last_audio_online_status = audio_online_status;
        display_action_t audio_action = audio_online_status ? D_A_ON : D_A_OFF; 
        display.updateContent(D_E_AUDIO, audio_action);
    }
}

void ClockMachine::buttonShortPressed() {
    state->buttonShortPressed(this);
}

void ClockMachine::buttonLongPressed() {
    state->buttonLongPressed(this);
}

void ClockMachine::encoderRotated(rotary_encoder_pos_t position, rotary_encoder_dir_t direction) {
    state->encoderRotated(this, position, direction);
}

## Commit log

2022-02-18 A couple of settings and defines added, settings are also now read and saved in NVS
2022-03-03 Changed pull mode for button pin to avoid an additional resistance in the circuit
2022-03-27 Swapped pins a and b in rotary encoder implementation, it was wrong due to bad wiring
2022-06-06 Remove RG LEDs and use pins I04 and I05 for the MP3 player as per HW design 1.1
2022-06-28 Added additional parameter to invert button logic of rotary encoder if necessary, which is necessary now for the new encoder I am using
    [clock_common.hpp, main.cpp]
2022-06-30 Forgotten to add this in the inverted button commit
    [main.cpp]
2022-06-30 Code slightly besser structured and the encoder rotation now increases the brightness in normal time mode
2022-07-06 Fixed issue with not updated display after deactivating alarm when snooze state is exited
    [clock_machine_states.cpp]
2023-03-07 Removed deprecated ADC functions and replaced with current ones
    [clock_common.hpp]
2023-03-09 Added visualization of remaining bed time until alarm triggers
2023-03-10 Small fix in the volume handling
    [clock_machine_states.cpp]
2023-03-10 Fixed small problem of last fix for volume handling
    [clock_machine_states.cpp]
2023-03-10 Added symbol for audio problems and small cleanup
    [clock_machine.cpp]
2023-03-10 Added an overload of Display::updateContent to avoid unnecessary calls with dummy NULL values
    [clock_machine.cpp, clock_machine_states.cpp]
2023-03-11 Updated the preliminary README.md file to a more current status of the project
2023-03-11 Enabled config option CONFIG_NEWLIB_NANO_FORMAT to switch newlib to the “nano” formatting mode and thus save approx. 3KB of flash as explained in https://docs.espressif.com/projects/esp-idf/en/latest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
2023-03-12 Remove obsolete LEDC code
2023-03-12 Added a conditional define to avoid compilation and usage of MQTT functionality if not desired
    [clock_machine.cpp, clock_machine_states.cpp, display.cpp]
2023-03-12 Fixed bug in time update function which prevented the proper update of bed time
    [clock_machine.cpp]
2023-03-15 Updated hardware documentation with 3D printed case details
    [case.stl, knurled_button.stl, rear_cover.stl]
2023-03-16 Fixed case.stl
    [case.stl]
2023-03-18 Replaced ESP-32S-C3 Kit with Seeed Studio XIAO ESP32C3, new platformio config and new pin assignments
    [clock_common.hpp]
2023-03-18 Updated schematics and PCB for new revision 2.0
2023-03-18 Documentation changes for new ESP32C3 used
2023-03-24 Fixed undesired direct transition from alarm to time state by rotating the encoder
    [clock_machine_states.cpp]
2023-03-24 Fixed undesired direct transition from alarm to time state by rotating the encoder
    (cherry picked from commit aeb9c4a95798db7812e42fb645f7b02767b85b86)
    [clock_machine_states.cpp]
2023-04-02 Updated 3D files and hardware documentation
    [case.f3z, case.stl, knurled_button.stl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]
